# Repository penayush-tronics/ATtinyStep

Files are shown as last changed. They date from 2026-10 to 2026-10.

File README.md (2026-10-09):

# ATtinyStep

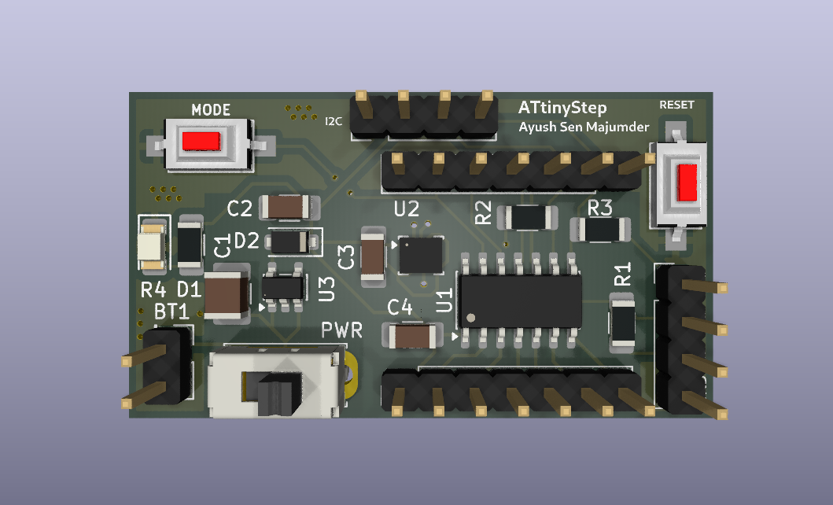
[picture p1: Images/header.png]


ATtinyStep is a compact, rechargeable, and portable offline step counter as well as speedometer. It helps in reaching your step goals at a healthy pace, while enjoying the outside world instead of doomscrolling with your neck down. It uses a 6-axis Accelrometer+Gyro IMU (Interital Measurment Unit) and the processing capabilities of the ATtiny1624 to easily count your steps automatically. As a bonus, it doubles as breakout board for the ATtiny1624, so it can be used for more projects other than a speedometer.

## How to use the ATtinyStep
Here is a labelled diagram:

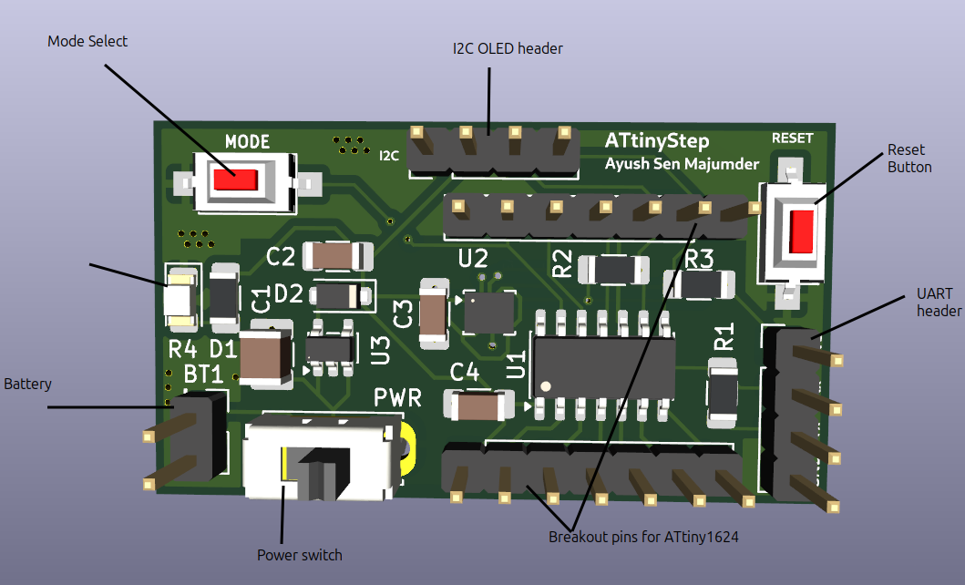
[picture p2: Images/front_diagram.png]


#### As step counter
Connect a single cell 3.7V li-ion battery to the battery header (with correct polarity; labelled on the back). It has an built-in voltage. After that, connect the I2C OLED screen. To use it as a step counter, flip the switch to turn it on. 
On the top left corner is a Mode select button, which allows the selection between speed display and step counting modes.
On the top right corner there is a Reset button to reset the Attiny chip in case of some error/restart. Below this button is the UART programming header, labelled for convenience. 
The device will automatically start counting steps and calculating the speed of your walking or any motion. 

#### As development board
You can also use it as a breakout board for the ATtiny1624 with built in 6-axis Gyro+Accelerometer and easy to use I2C header.
When powering it as a development board, make sure to use only **3V3 power (3.3V)**, on the VCC pin either on the breakout pins, the programming header, or the I2C header. Make sure to connect GND-Ground too. **Be careful with polarity**.
Pins 8 and 9 are always pulled high due to the I2C, so use them primarily for I2C. 
Pin 13 is connected to the onboard Mode Select button, using active low. This pin can be reconfigured.
Use the reset button to restart the Attiny1624.

#### Programming
ATtinyStep uses UPDI programming for the ATtiny1624, via UART. Make sure to use 3V3 only.
An appropriate resistor is already placed in series with Tx, so an external series resistor is not required, only a UART to USB converter is needed for programming. 
Connect the GND VCC pins, and connect **UART-USB Rx to ATtinyStep Tx, and Tx to Rx, like cris-cross**.
After that it can be programmed using ArduinoIDE with the **MegaTinyCore board library**.   

### Labels
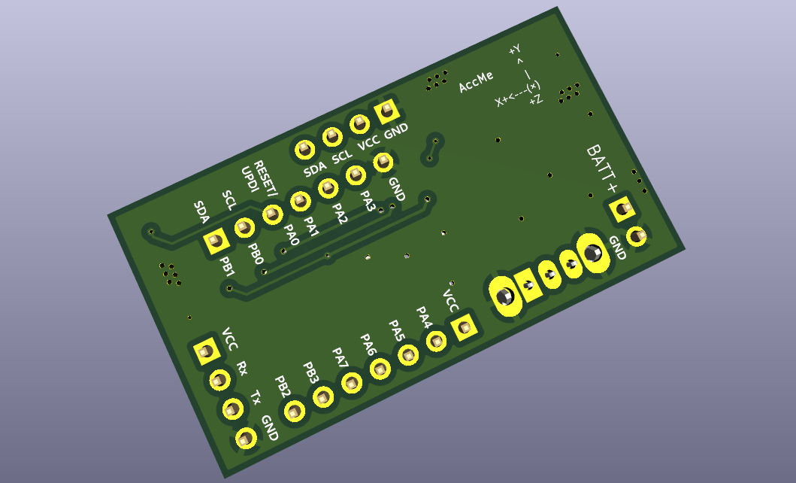
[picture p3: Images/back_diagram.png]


The board is thoroughly labelled with all components and pins labelled.
Here you can see the breakout pin labels, header labels, battery label **-- PLEASE DONT PUT REVERSE POLARITY--** , and accelerometer direction label.
Use these as a guide for usage. 

## How does it work
The ATinyStep works by letting the ATtiny1624 continuously gather angular orientation and acceleration data. By comparing these continuous values to known patterns, such as walking with it in your hand or pocket, it can accuratley detect a step. These actions create very specific accelration and rotation patterns, hence they can be used as reference. For example, walking with it in your hand will result in a big arc-like path, with maximum acceleration at the edges of the arc, and least in the center. This also is how your mobile device, like a phone, counts steps. The sensor being used here is from the LSM6DS series by STMicroelectronics, where the 6 stands for 6-axis. Six-axis means three-axis accelrometer and three-axis gyroscope. 

## Schematics 
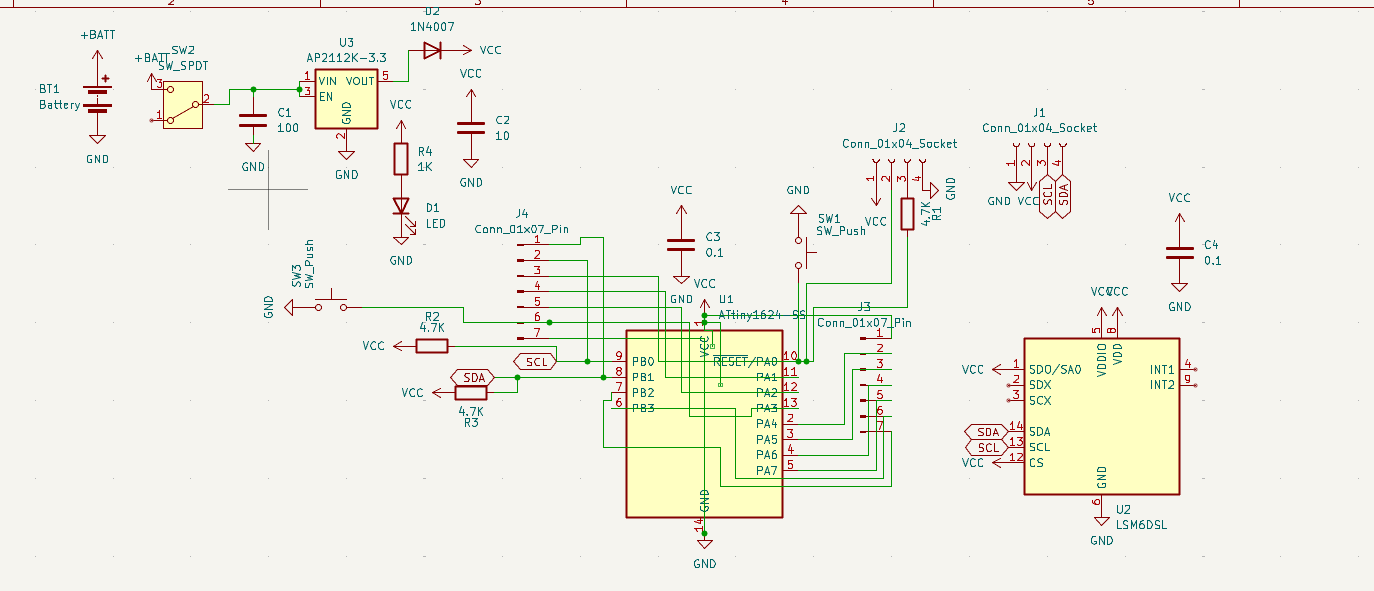
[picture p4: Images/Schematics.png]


KiCAD schematics can be found [here](PCB_Files/ATtinyStep.kicad_sch)

## PCB design

#### Front side:
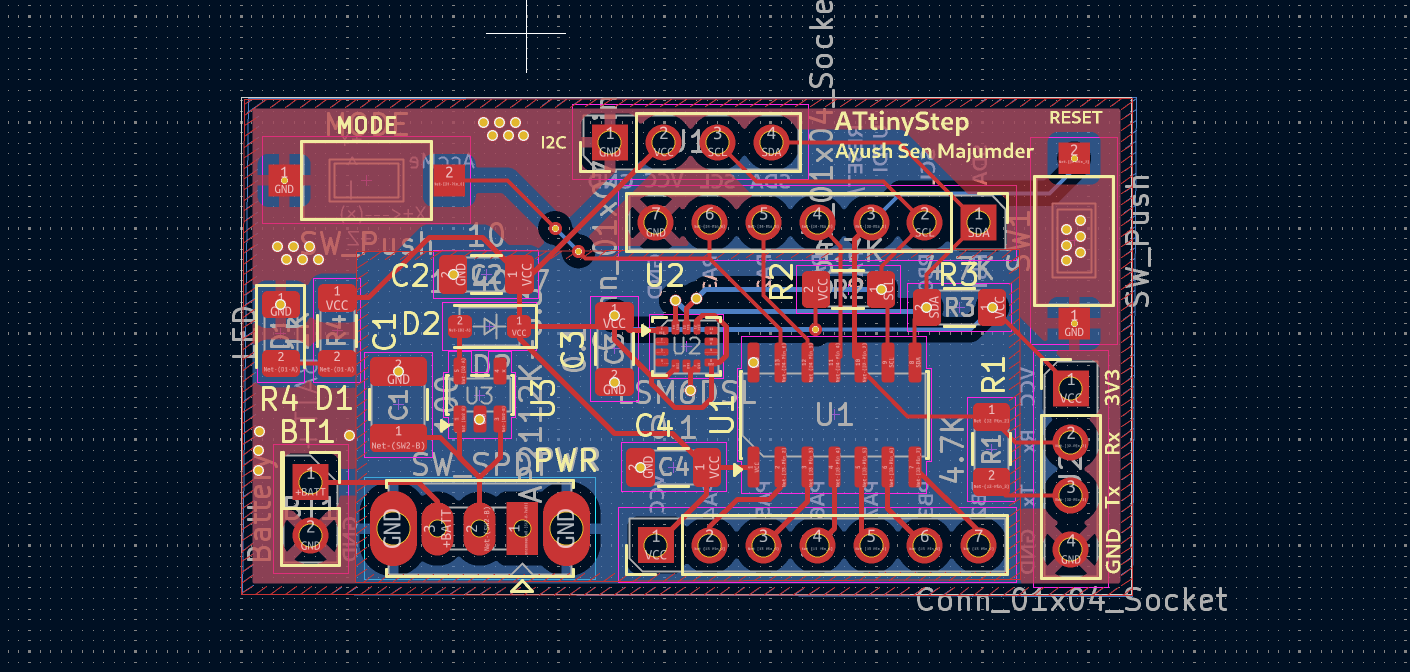
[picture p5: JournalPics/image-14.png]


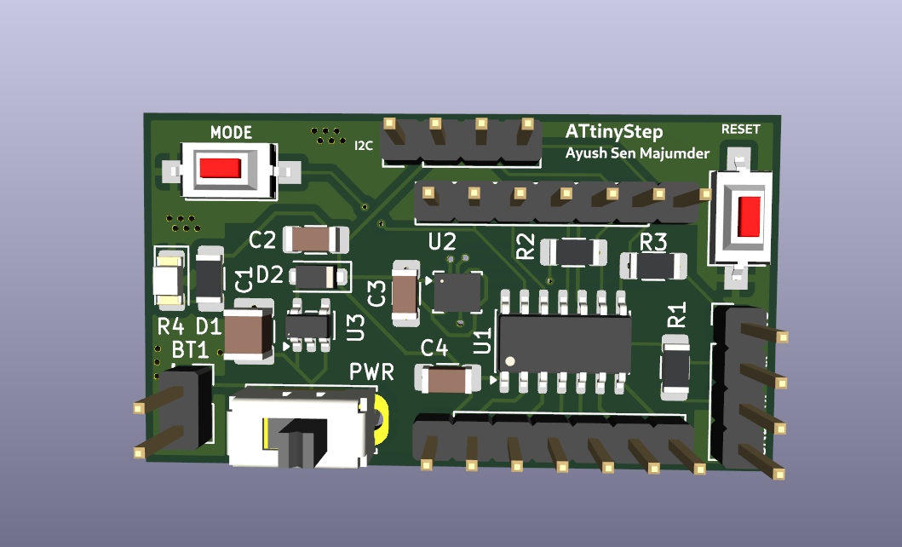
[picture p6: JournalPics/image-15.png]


#### Back side:
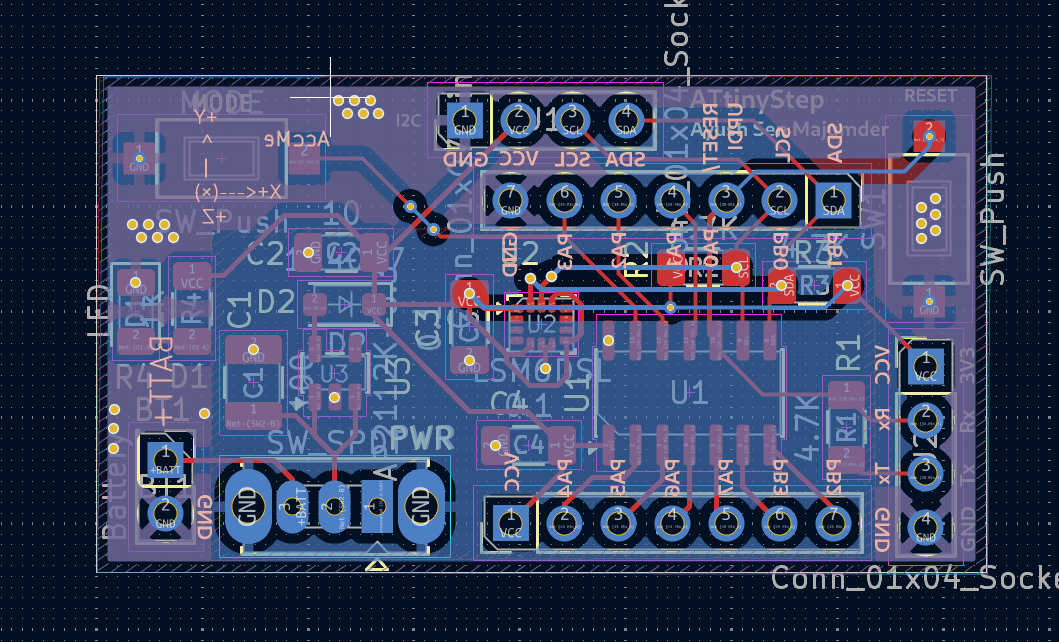
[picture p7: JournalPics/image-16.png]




KiCAD PCB design can be found [here](PCB_Files/ATtinyStep.kicad_pcb).
Gerber files for fabrication are [here](PCB_Files/ATtinyStep-Gerbers.zip).
Position file for pick and place is [here](PCB_Files/ATtinyStep-all.pos).

## Why ATtinyStep exists
One day I was walking around my community and talking to my friend online. We were talking about walking as an exercise, and how walking faster is important. Hence, they said that they were sure I wasn't walking fast enough. I told them I walk at 6km/h, but they did not believe me. That day I had two realisations: I should take a break from my phone during walks, and I need a speedometer for myself. So, this idea was born. An offline hardware speedometer. So I can make sure I am walking at a healthy speed.
The name comes from when I was thinking about a title, and realised ATtiny sounds like 'A tiny', and well it's a step counter. So ATtinyStep came. It is pronounced 'Ay Tee tiny step' or just 'A tiny step'.

The extra breakout board pins were because it felt like a waste to have so many pins unused. So the breakout enables them to be used. 

## Demo
Coming soon :)

## Bill Of Materials (BOM)

| Sr No. | Component Description | Min Order Qty | Qty for Board | Unit Price (INR) | Ext. Price (INR) | Reference Link |
|---|---|---|---|---|---|---|
| 1 | ATTINY1624-SSU-MICROCHIP-8 Bit MCU | 1 | 1 | 226.00 | 226.00 | [Robu](https://robu.in/product/attiny1624-ssu-microchip-8-bit-mcu-avr-family-attiny1624-series-microcontrollers-avr-20-mhz-16-kb-14-pins-wsoic/) |
| 2 | LSM6DSOETR3-Stmicroelectronics | 1 | 1 | 292.00 | 292.00 | [Robu](https://robu.in/product/lsm6dsoetr3-stmicroelectronics-lsm6dsoetr3-mems-modules/) |
| 3 | 0.96 inch Yellow-Blue OLED Display Module | 1 | 1 | 179.00 | 179.00 | [Robu](https://robu.in/product/0-96-inch-yellow-yellow-blue-oled-lcd-led-display-module/) |
| 4 | AP2112K/AP2125K -3.3TRG1-Diodes Incorporated | 1 | 1 | 13.00 | 13.00 | [Robu](https://robu.in/product/ap2125k-3-3trg1-diodes-incorporated-300ma-65db-fixed-3-3v-positive-9v-sot-23-5-voltage-regulators-linear-low-drop-out-ldo-regulators-rohs/) |
| 5 | 3.7V 1500mAH Li-Po Rechargeable Battery (523450) | 1 | 1 | 232.00 | 232.00 | [Quartz Components](https://quartzcomponents.com/products/3-7v-1500mah-li-po-rechargeable-battery-523450?variant=44853316813034) |
| 6 | Toggle Slide Switch | 1 | 1 | 5.00 | 5.00 | [Quartz Components](https://quartzcomponents.com/products/toggle-slide-switch?variant=31898088833159) |
| 7 | Green LED - SMD (1206 Package) - Pack of 50 | 50 | 1 | 0.72 | 36.00 | [Quartz Components](https://quartzcomponents.com/collections/all/products/green-led-smd-1206-package-pack-of-50) |
| 8 | 1K Ohm 1206 Package 1/4W SMD Resistor 5% Tolerance (Pack of 20 Pieces) | 20 | 1 | 0.50 | 10.00 | [Quartz Components](https://quartzcomponents.com/products/1k-ohm-1206-package-1-4w-smd-resistor-5-tolerance-pack-of-20-pieces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) |
| 9 | 4.7K Ohm 1206 Package 1/4W SMD Resistor 5% Tolerance (Pack of 20 Pieces) | 20 | 3 | 0.60 | 12.00 | [Quartz Components](https://quartzcomponents.com/products/4-7k-ohm-1206-package-1-4w-smd-resistor-5-tolerance-pack-of-20-pieces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) |
| 10 | TSB005A2518B-BZCN-3.6mm 2.5mm 50mA 8mm 30,000 Times 180gf 12V SMD Tactile Switches | 4 | 2 | 2.85 | 11.40 | [Robu](https://robu.in/product/tsb005a2518b-bzcn-3-6mm-2-5mm-50ma-8mm-30000-times-180gf-12v-smd-tactile-switches-rohs/) |
| 11 | A7 / 1N4007 SMD Diode (Pack of 10) | 10 | 1 | 1.10 | 11.00 | [Quartz Components](https://quartzcomponents.com/products/m7-1n4007-smd-diode-pack-of-11?variant=43690452713706) |
| 12 | 100nF / 0.1uF (104) 50V 1206 SMD Capacitor (Pack of 10 Pieces) | 10 | 2 | 1.60 | 16.00 | [Quartz Components](https://quartzcomponents.com/products/100nf-0-1uf-104-50v-1206-smd-capacitor-pack-of-10-pieces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) |
| 13 | 16V 10uF X5R 1206 Multilayer Ceramic Capacitors MLCC | 3 | 2 | 4.57 | 13.71 | [Robu](https://robu.in/product/cl31a106kohnnwe-samsang-16v-10uf-x5r-1206-multilayer-ceramic-capacitors-mlcc-smd-smt-rohs/) |
| 14 | MLCC SMD Capacitor - 100UF, 10V, 1210 | 1 | 1 | 46.00 | 46.00 | [Robu](https://robu.in/product/lmk325abj107mm-p-taiyo-yuden-cap-smd-mlcc-100uf-10v-1210-pack-of-1/) |
| 15 | TP4056 - Battery Charging | 1 | 1 | 14.00 | 14.00 | [Quartz Components](https://quartzcomponents.com/products/tp4056-battery-charging-micro-usb) |
| 16 | Male/Female headers | 1 | 1 | 9.00 | 9.00 | [Robu](https://robu.in/product/2-54mm-1x40-pin-male-single-row-straight-short-header-strip-pack-of-3/) |
| 17 | Custom PCB | 5 | 1 | 188.80 | 944.00 | [Lion Circuits](https://www.lioncircuits.com/quote?layers=2&units=5&dimensionX=50&dimensionY=20) |
|  | Totals: |  | 22 | 1226.96 | 2070.11 |  |

Price per board: ~1230 INR or ~ $12.9 USD

The spreadsheet BOM is [here](ATtinyStepBOM.xlsx)

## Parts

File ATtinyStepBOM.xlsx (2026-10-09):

Sr No. | Component Description | Min Order Qty | Qty for board | Unit Price (INR) | Ext. Price (INR) | Reference Link
1 | ATTINY1624-SSU-MICROCHIP-8 Bit MCU | 1 | 1 | 226 | 226 | https://robu.in/product/attiny1624-ssu-microchip-8-bit-mcu-avr-family-attiny1624-series-microcontrollers-avr-20-mhz-16-kb-14-pins-wsoic/
2 | LSM6DSOETR3-Stmicroelectronics | 1 | 1 | 292 | 292 | https://robu.in/product/lsm6dsoetr3-stmicroelectronics-lsm6dsoetr3-mems-modules/
3 | 0.96 inch Yellow-Blue OLED Display Module | 1 | 1 | 179 | 179 | https://robu.in/product/0-96-inch-yellow-yellow-blue-oled-lcd-led-display-module/
4 | AP2112K/AP2125K -3.3TRG1-Diodes Incorporated | 1 | 1 | 13 | 13 | https://robu.in/product/ap2125k-3-3trg1-diodes-incorporated-300ma-65db-fixed-3-3v-positive-9v-sot-23-5-voltage-regulators-linear-low-drop-out-ldo-regulators-r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
5 | 3.7V 1500mAH Li-Po Rechargeable Battery (523450) | 1 | 1 | 232 | 232 | https://quartzcomponents.com/products/3-7v-1500mah-li-po-rechargeable-battery-523450?variant=44853316813034
6 | Toggle Slide Switch | 1 | 1 | 5 | 5 | https://quartzcomponents.com/products/toggle-slide-switch?variant=31898088833159
7 | Green LED - SMD (1206 Package) - Pack of 50 | 50 | 1 | 0.72 | 36 | https://quartzcomponents.com/collections/all/products/green-led-smd-1206-package-pack-of-50
8 | 1K Ohm 1206 Package 1/4W SMD Resistor 5% Tolerance (Pack of 20 Pieces) | 20 | 1 | 0.5 | 10 | https://quartzcomponents.com/products/1k-ohm-1206-package-1-4w-smd-resistor-5-tolerance-pack-of-20-pieces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
9 | 4.7K Ohm 1206 Package 1/4W SMD Resistor 5% Tolerance (Pack of 20 Pieces) | 20 | 3 | 0.6 | 12 | https://quartzcomponents.com/products/4-7k-ohm-1206-package-1-4w-smd-resistor-5-tolerance-pack-of-20-pieces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
10 | TSB005A2518B-BZCN-3.6mm 2.5mm 50mA 8mm 30,000 Times 180gf 12V SMD Tactile Switches | 4 | 2 | 2.85 | 11.4 | https://robu.in/product/tsb005a2518b-bzcn-3-6mm-2-5mm-50ma-8mm-30000-times-180gf-12v-smd-tactile-switches-rohs/
11 | A7 / 1N4007 SMD Diode (Pack of 10) | 10 | 1 | 1.1 | 11 | https://quartzcomponents.com/products/m7-1n4007-smd-diode-pack-of-11?variant=43690452713706
12 | 100nF / 0.1uF (104) 50V 1206 SMD Capacitor (Pack of 10 Pieces) | 10 | 2 | 1.6 | 16 | https://quartzcomponents.com/products/100nf-0-1uf-104-50v-1206-smd-capacitor-pack-of-10-pieces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
13 | 16V 10uF X5R 1206 Multilayer Ceramic Capacitors MLCC | 3 | 2 | 4.57 | 13.71 | https://robu.in/product/cl31a106kohnnwe-samsang-16v-10uf-x5r-1206-multilayer-ceramic-capacitors-mlcc-smd-smt-rohs/
14 | MLCC SMD Capacitor - 100UF, 10V, 1210 | 1 | 1 | 46 | 46 | https://robu.in/product/lmk325abj107mm-p-taiyo-yuden-cap-smd-mlcc-100uf-10v-1210-pack-of-1/
15 | TP4056 - Battery Charging | 1 | 1 | 14 | 14 | https://quartzcomponents.com/products/tp4056-battery-charging-micro-usb
16 | Male/Female headers | 1 | 1 | 9 | 9 | https://robu.in/product/2-54mm-1x40-pin-male-single-row-straight-short-header-strip-pack-of-3/
17 | Custom PCB | 5 | 1 | 188.8 | 944 | https://www.lioncircuits.com/quote?layers=2&units=5&dimensionX=50&dimensionY=20
 | Totals: |  | 22 | 1226.96 | 2070.11

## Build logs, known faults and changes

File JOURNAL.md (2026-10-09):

---
title: "ATtinyStep"
author: "Ayush Sen Majumder"
description: "An ATtiny powered step counter and speed/distance measuring device that fits in the palm of your hand."
created_at: "2026-10-05"
---

# October 5

After a few days of rumination, my idea for this step counter is finally refined and ready for me to pursue. My inital idea was just a device to tell me how fast I was walking during my exercise, because speed does matter. Incline too. Hence  this idea came. After some thinking I thought of adding some step counting, distance measuring too. 

Now that requried features are there, I needed a cheap and appropriate processor. An arduino nano is too over-powered for this, while a ATtiny13a does not have enough ram. So I researched and found the ATtiny16 series, which has 16KB of flash and 2KB of memory. 

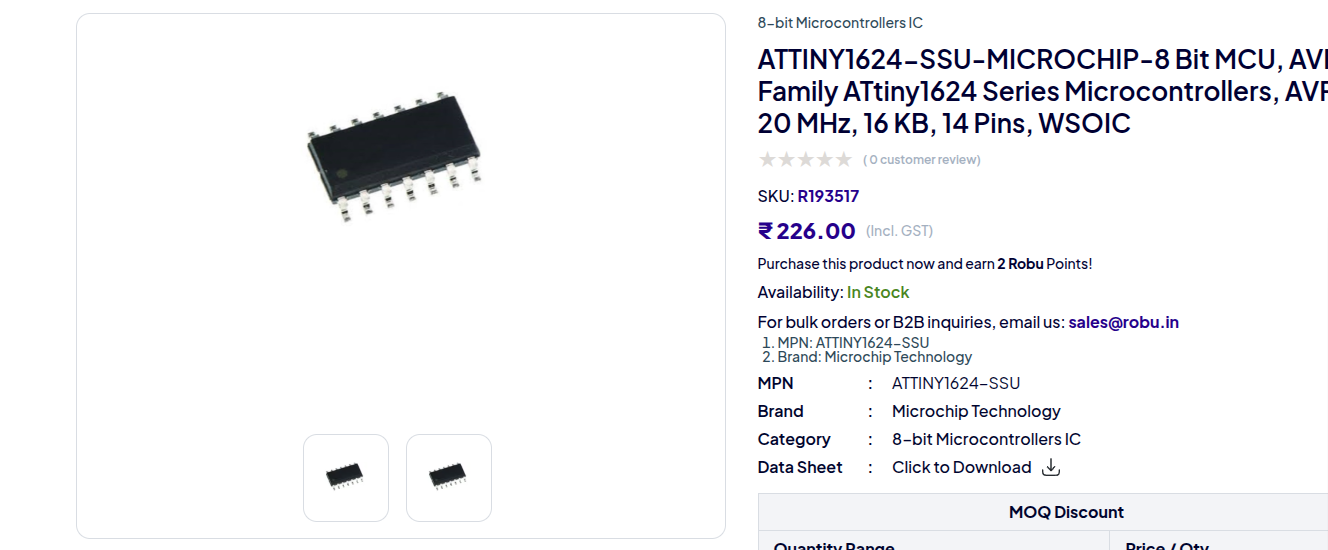
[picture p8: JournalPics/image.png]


It is perfect for the needed calculations, as well as being simple enough for this project. Some other versionsa re there like the ATtiny8 series, but the RAM is not enough in some cases, and in others the price is more than this ATtiny1624. 

It has I2C, which means I can eaisly use peripherals. I wanted to use an I2C OLED screen for output, hence this is perfect. 

To measure all speed, steps, and distance, I need an IMU or an Intertial Meausrment Unit. For this project I need a 6-axis IMU, meaning a 3-axis accelerometer as well as a 3-axis gyroscope. The cheapest one I could find was the LSM6DS series: 

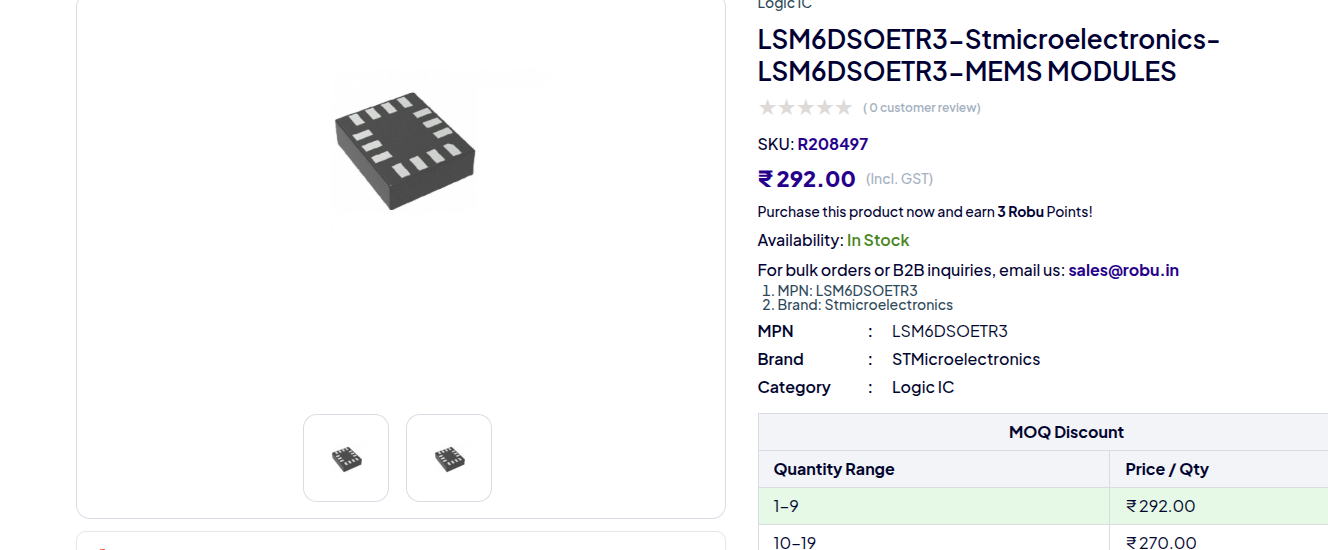
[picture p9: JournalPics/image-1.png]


For some weird reason, IMUs are insanely expensive. Tough to find a cheap one thats 6-axis. This one is LGA, which I have never soldered before, so this will be a new challenge for me. 

Next I will do the schematics and then build pcb. After that I need funding to order parts and PCB, then I can build this project and use it. The plan is pretty clear, and im aching to execute it. 

Note: I did not know i needed a Lapse timelapse for research, so there is no lapse for this. 

**Total time spent: 1 hour**

# October 6

## Making schematics

Today I made the schematic for the device. I thought it wouldn't be that much of a hassle, but it was nonetheless. I forgot i needed a power circuit, because i thought everything would work off of a LiPo, and also realised there were so many pins on the ATtiny going to waste. 

Here is the schematic right now: 

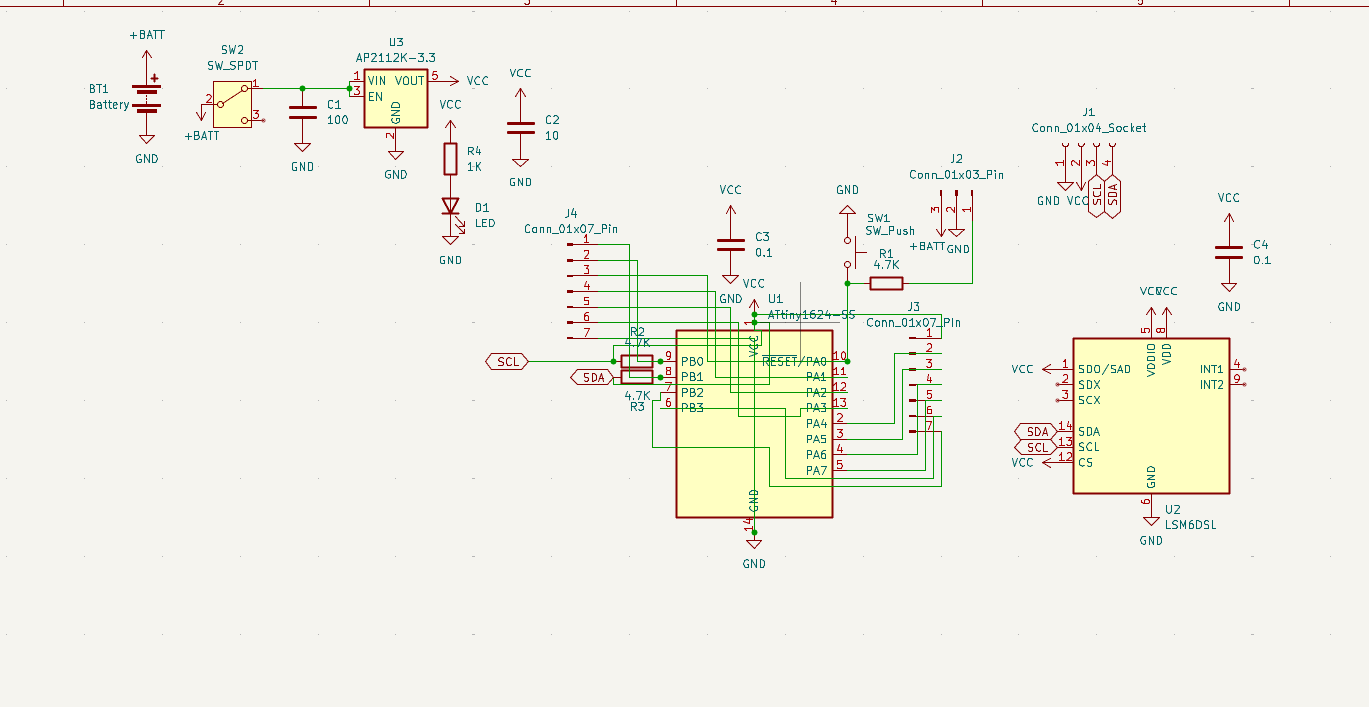
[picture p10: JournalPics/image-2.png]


In the top left corner is a simple standard power circuit: 

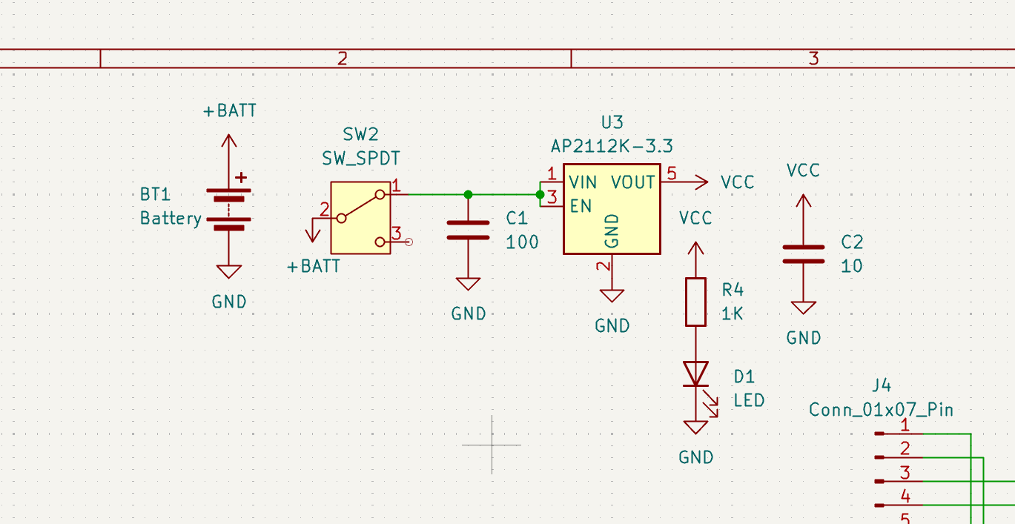
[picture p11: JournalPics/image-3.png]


I am using an AP2112K-3.3V LDO to step down the battery voltage to 3.3V. Along with this is a switch, some capacitors and a status LED. 
Had to add this because the IMU will no work off the battery directly, too high of a voltage. 

Next i added schematics for the ATtiny1624:

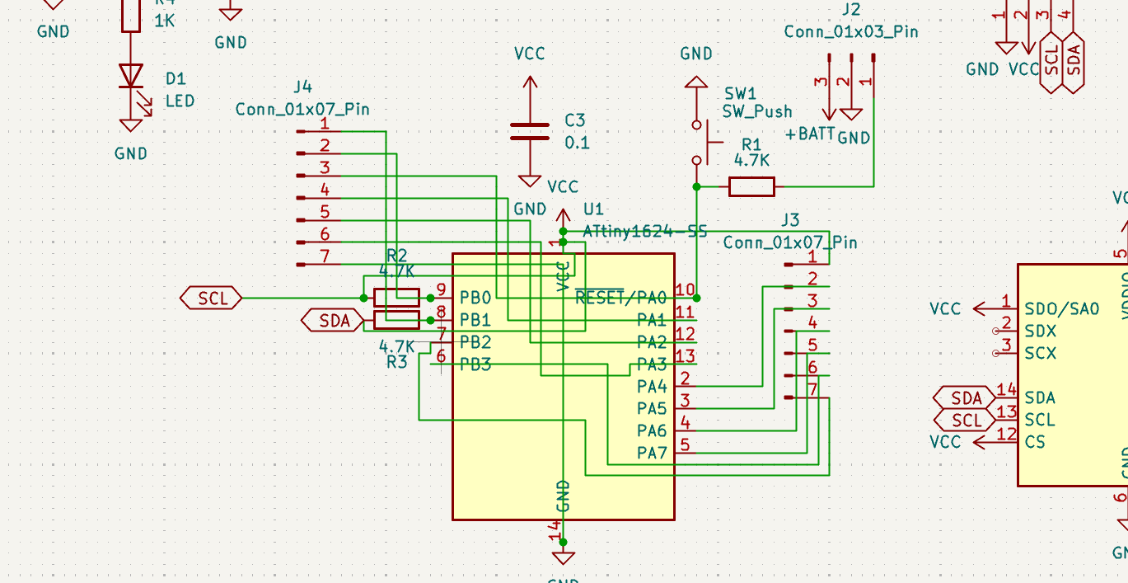
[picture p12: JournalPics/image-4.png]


Wired up a reset button, a programming header, the I2C lines for OLED and IMU. Added resistors for the I2C and UPDI programming. I also added some breakout pins because it felt like the rest of the chip was going to waste when im using just 2 pins to drive peripherals. so an optional breakout is there now. Hence the mess of wires. 

Finally schematics for the IMU: 

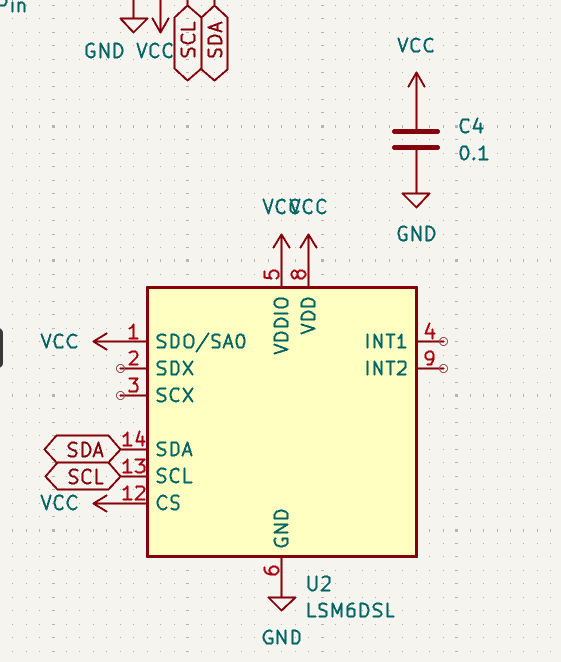
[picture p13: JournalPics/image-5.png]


Just two I2C pins, and every other connection is pulled high for the correct setup. 

Thats about it for the schematic, ill make the PCB next

Lapse: https://lapse.hackclub.com/timelapse/I2aO08c73dfr

**Total time spent: 1 hour**

# October 7

## Designing PCB

I designed the PCB today. It tooke me a while to design this because I had to really do a lot of space management. For the current deisgn I am 'satisfied' but I think it can be better. I only made it single sided so i can solder it usign just my hotplate; no double side hassle even thought double might have been easier to design. 
Here is the PCB:
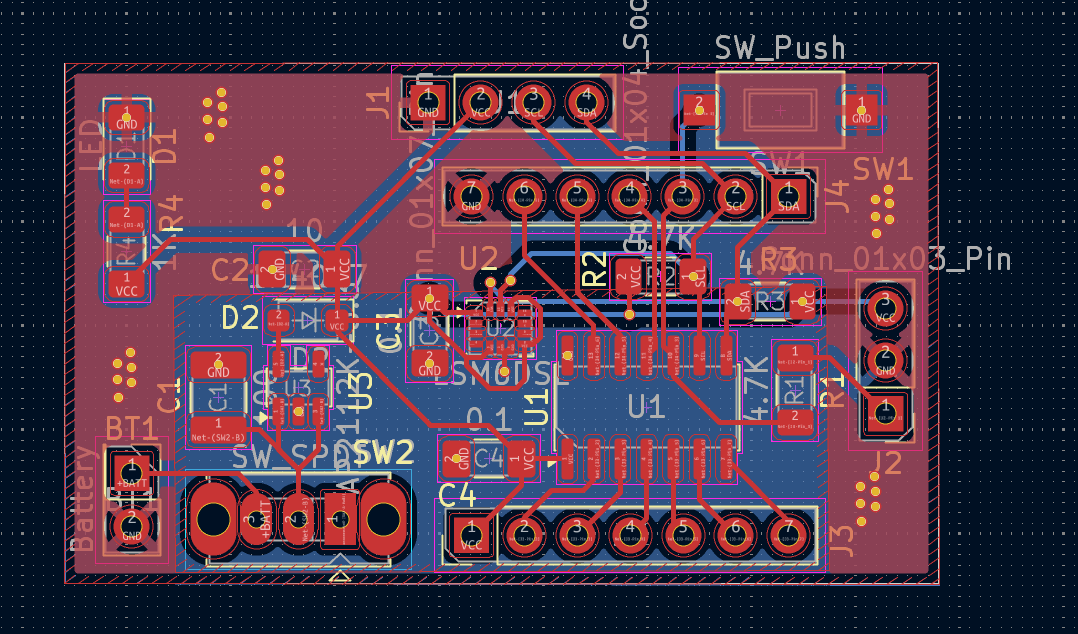
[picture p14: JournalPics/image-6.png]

Added a few parts like a switch, to turn the device on and off. 

I also added a diode:
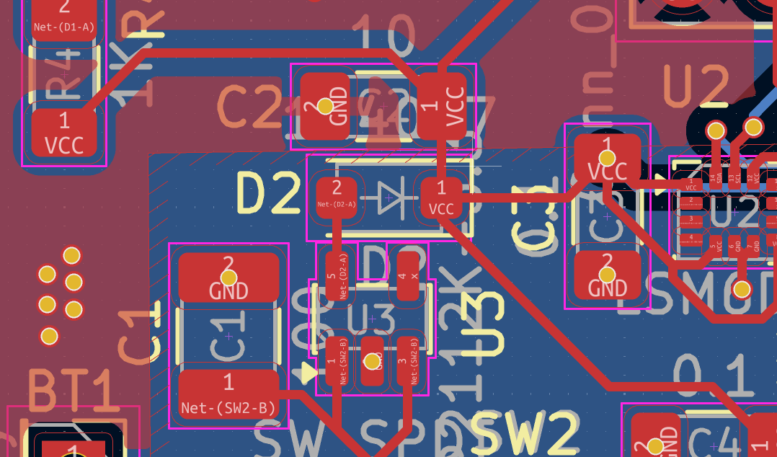
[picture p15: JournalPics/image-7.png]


this diode prevents current from entering the LDO in reverse when it's powered by the programmer on the programmign header. 
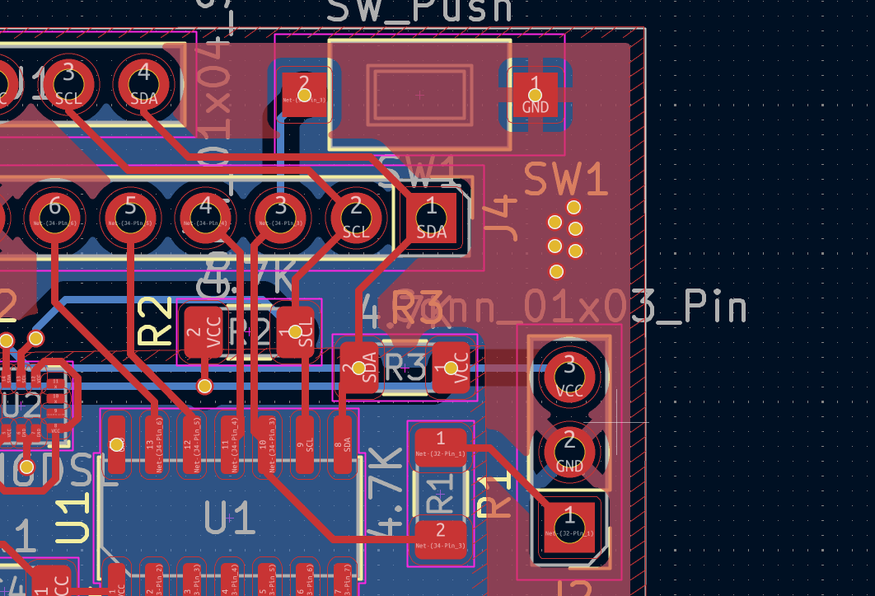
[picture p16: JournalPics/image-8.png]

The right three-pin is the programming header, the top button is a reset button for the ATtiny. Up there is a four-pin for the OLED screen. 

The most annoyign part was wiring the I2C lines. I had to route them from the back which was annoying and felt asymmetrical. 
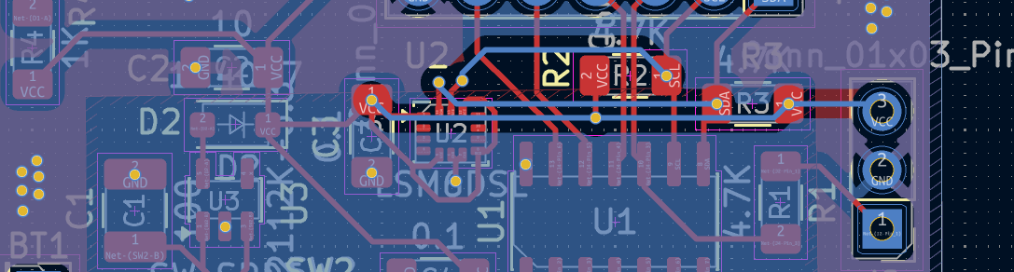
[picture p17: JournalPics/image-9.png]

As you can see, where blue is backside. 

Another annoying thing was power VCC connections. I couldnt use a power plane because ground plane more important, and frontside there is no place for a power plane. I actually had to remove a rectangle of the ground plane because it had thin parts which would only capture noise instead of remove it. 

A key thing which i did was to center the IMU. This is important for accurate angle readings and measuring acceleration. I did this by measuring the board dimensions and approximately halving them, and putting guides. 

Here is a 3d view: 
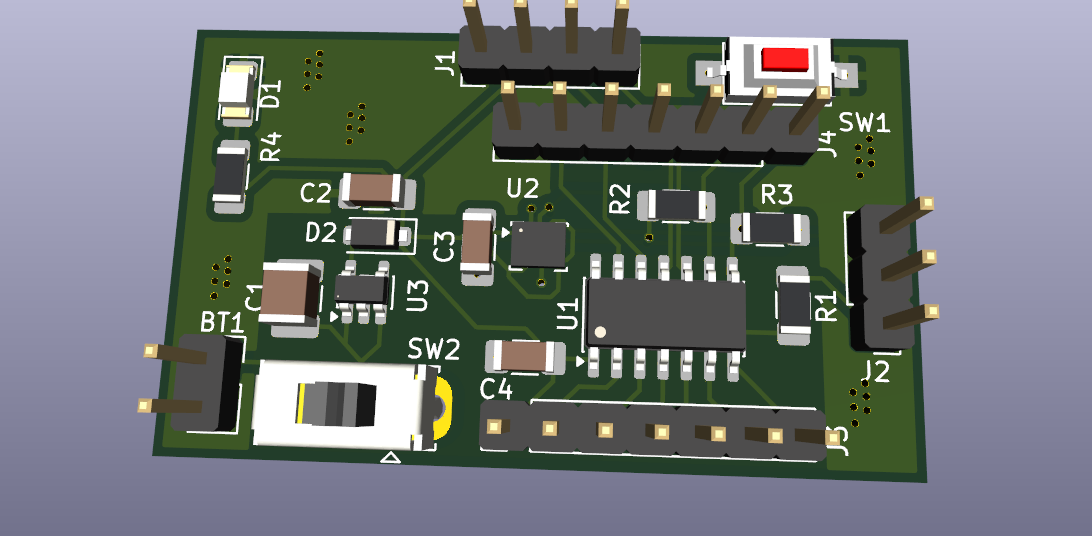
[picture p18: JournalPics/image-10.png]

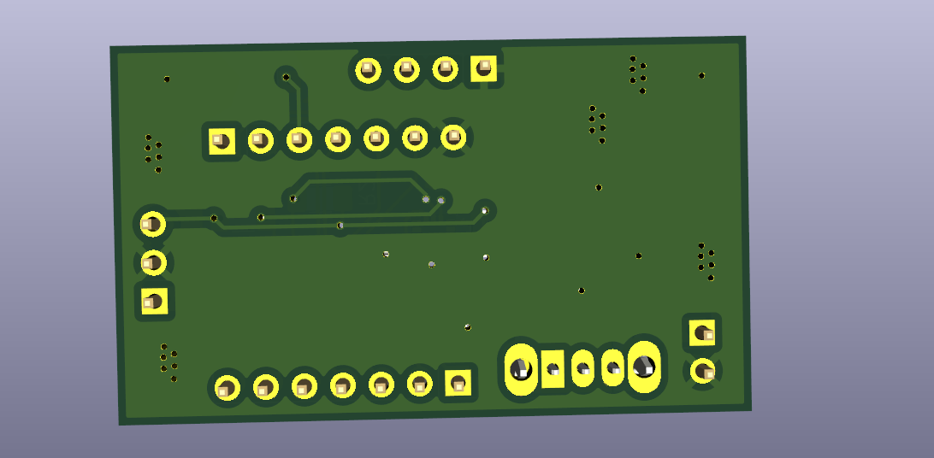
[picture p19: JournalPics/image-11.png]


Next is refining PCB, panelising for efficient fabrication, and then repo updating and shipping. 

Lapse: https://lapse.hackclub.com/timelapse/N_VsGccL-1x6

**Total time spent: 1.5 hours**

# October 8

  ## Fixing the PCB

I was looking over the PCB for some time, and there were a few crucial mistakes i had to fix, and i made the PCB smaller. I am actually happy with this design now, it looks much better than before. 
### Mistake 1: breakout pin placement
Before, the breakout pin placements were almost random. the two rows were not aligned with 2.54mm pitch standard. So i had to use another header row as a guide and arrange them. This meant i hd to brign the top one closer, so i had to rearrnage the I2C resistors. Now it is alligned!.

### Mistake 2: UPDI programming pins
I didnt realise UPDI programming puts a resistor only on the Tx, so i had placed a resistor in series with the UPDI pin itslef! It would have been impossible to program the chip if i had done that. I fixed it now by editing the schematics and adding Tx Rx pins, and adding a resistor to only the Tx.
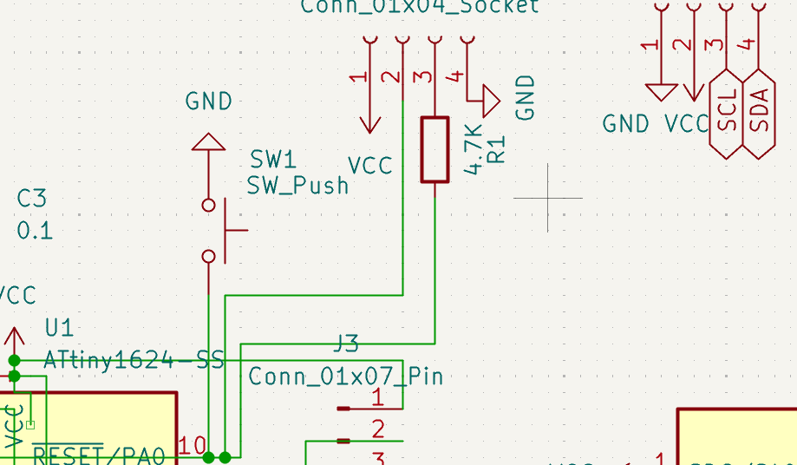
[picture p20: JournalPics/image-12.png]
 

### other edits
i resized the board to be smaller heightwise, because it just felt like a waste of space. I rearrnaged eveyrthing, i recentred the IMU, this time with much better accuracy. 
I added a mode select button to pin 6 on the attiny, so that it can be controlled a little. 
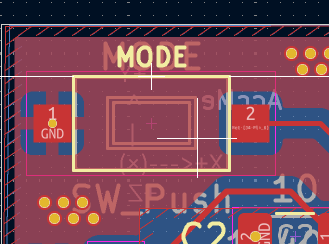
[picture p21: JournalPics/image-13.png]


it looks really nice now, especially because i labelled everything on the PCB. I added a accelrometer direction diagram too, some pin names and other things for usability and readability. Most importantly i added labels for battery input; reverse polarity would kill everything. 
 take a look at the updated PCB!

 front:
  
  
 
 back:
  
  

 I am really happy with this. Of course i will do another check before fabrication. But right now its beutiful. 

 Lapse: https://lapse.hackclub.com/timelapse/U3Mb4CTaFlST

**Total time spent: 1.5 hours**

# October 9
  ## Project is shipped on GitHub!
  I finally shipped the project on github. The BOM and everything is there i made BOM i made readme. Im too sleepy to write anything now. Hackatime and Lapse tracked me, but the README was also tracked by Hackatime at same time as Lapse. so ill deflate my jorunal time here so that the hackatime time is accurate and im not overstating time. 

  Here is the repo now:
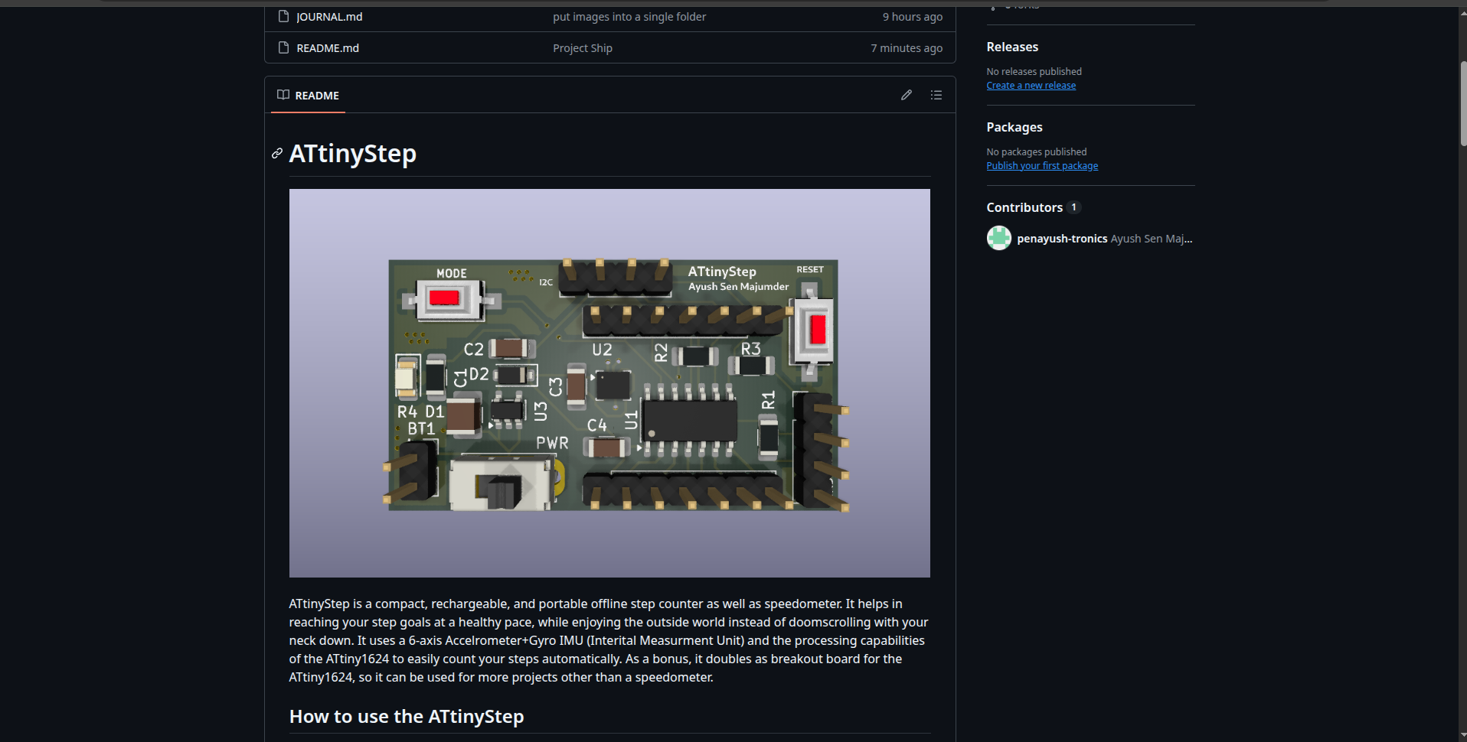
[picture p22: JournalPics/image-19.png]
  

   I added how to use:
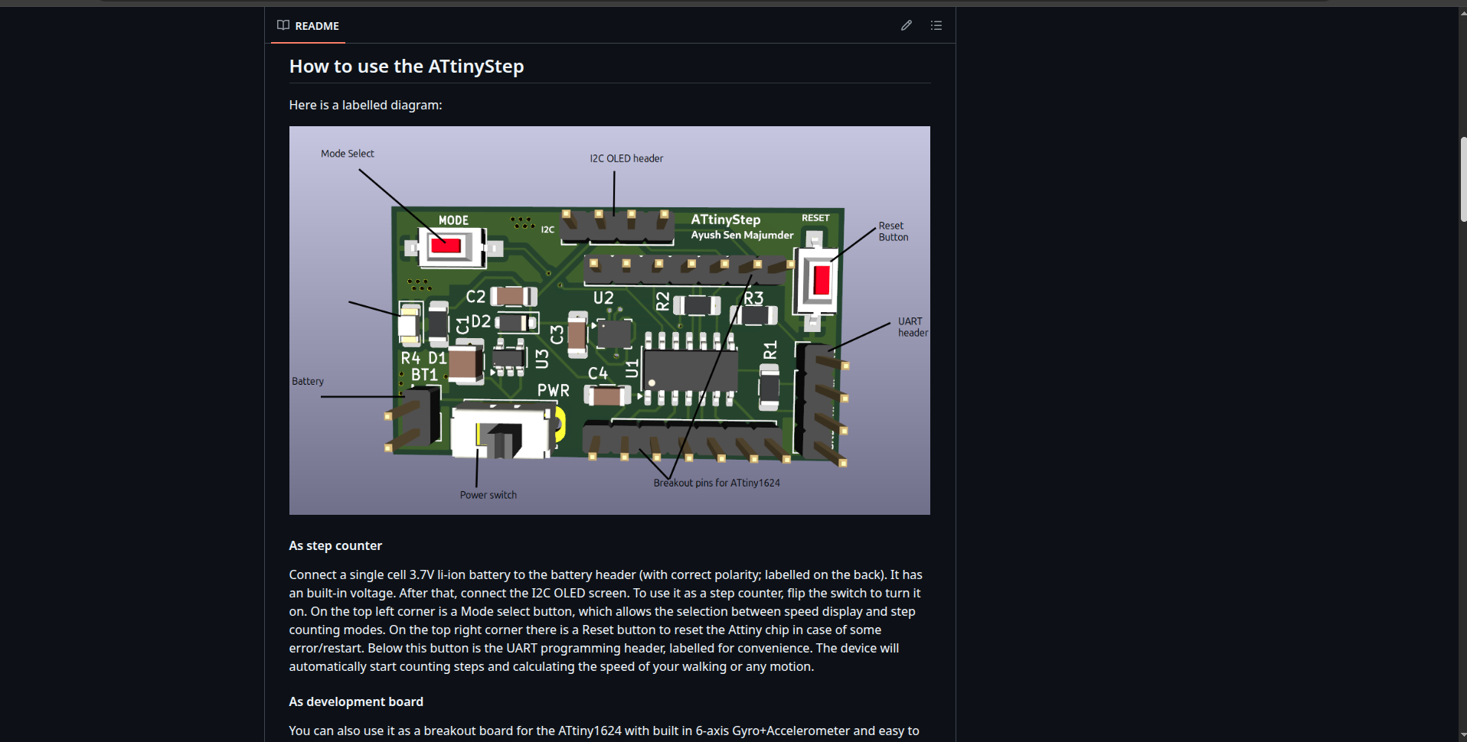
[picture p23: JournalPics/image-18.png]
   

   BOM:
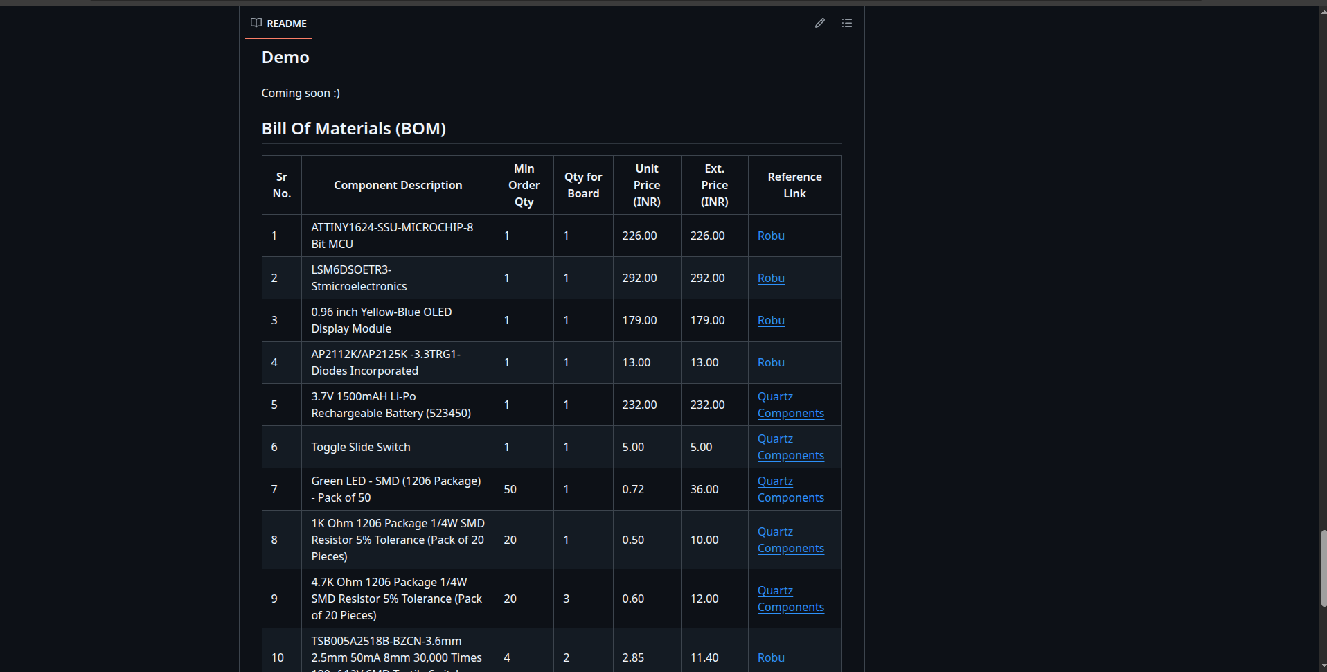
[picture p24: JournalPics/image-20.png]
   

   Lapse: https://lapse.hackclub.com/timelapse/evV-MM8G5bpx

   So i have 2h on lapse and 1h 24 min on hackatime for README. so 1.5h hackatime 0.5h journal rounded roughly.

**Total time spent: 0.5 hours**

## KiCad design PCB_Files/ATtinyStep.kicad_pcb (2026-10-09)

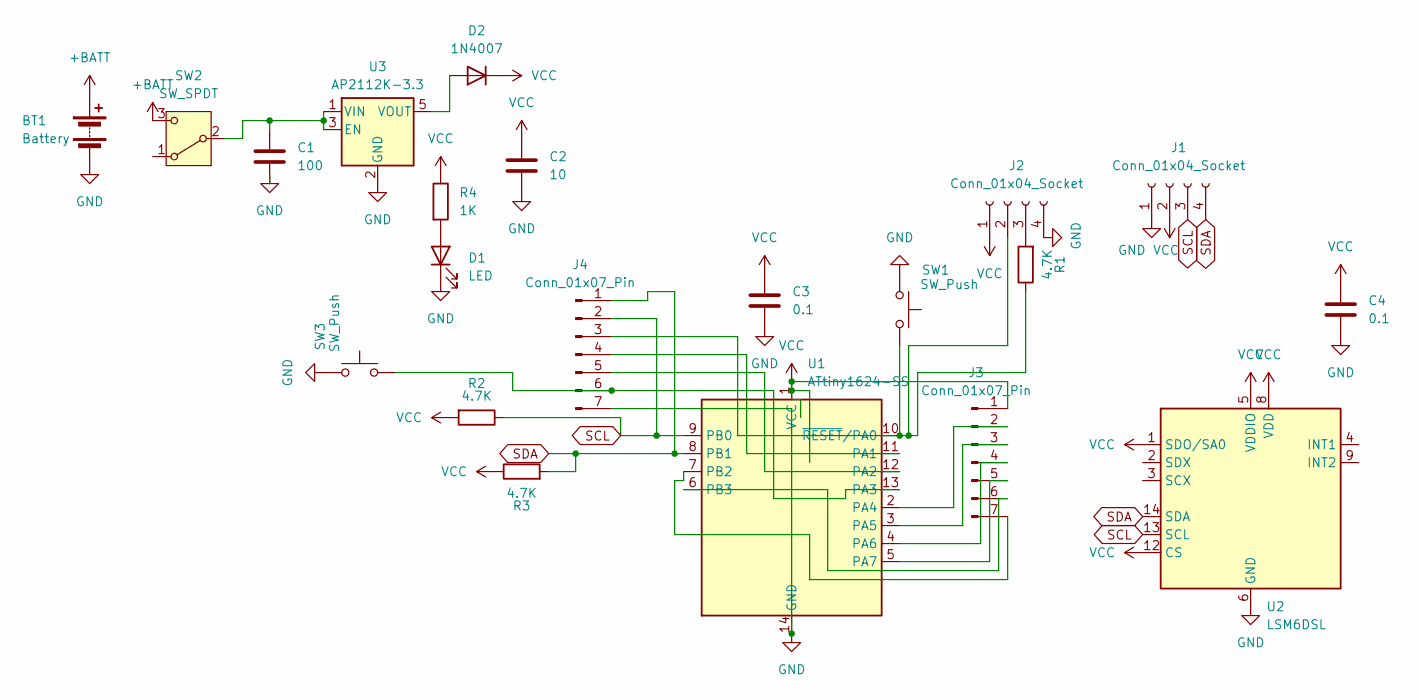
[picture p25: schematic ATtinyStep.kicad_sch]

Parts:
BT1: Battery; PinHeader_2x01_P2.54mm_Vertical
C1: 100; C_1210_3225Metric_Pad1.33x2.70mm_HandSolder
C2: 10; C_1206_3216Metric_Pad1.33x1.80mm_HandSolder
C3, C4: 0.1; C_1206_3216Metric_Pad1.33x1.80mm_HandSolder
D1: LED; LED_1206_3216Metric
D2: 1N4007; D_SOD-123F
J1, J2: Conn_01x04_Socket; PinHeader_1x04_P2.54mm_Vertical
J3, J4: Conn_01x07_Pin; PinHeader_1x07_P2.54mm_Vertical
R1, R2, R3: 4.7K; R_1206_3216Metric_Pad1.30x1.75mm_HandSolder
R4: 1K; R_1206_3216Metric_Pad1.30x1.75mm_HandSolder
SW1, SW3: SW_Push; SW_SPST_CK_RS282G05A3
SW2: SW_SPDT; SW_Slide_SPDT_Straight_CK_OS102011MS2Q
U1: ATtiny1624-SS; SOIC-14_3.9x8.7mm_P1.27mm
U2: LSM6DSL; LGA-14_3x2.5mm_P0.5mm_LayoutBorder3x4y
U3: AP2112K-3.3; SOT-23-5

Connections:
+BATT: BT1.1 (+), SW2.3 (C); also elsewhere on the board
GND: BT1.2 (-), C1.2, C2.2, C3.2, C4.2, D1.1 (K), J1.1, J2.4, J4.7, SW1.1, SW3.1, U1.14 (GND), U2.6 (GND), U2.7 (GND), U3.2 (GND); also elsewhere on the board
unnamed: D1.2 (A), R4.2
unnamed: D2.2 (A), U3.5 (VOUT)
unnamed: J2.2, J4.3, R1.1, SW1.2, U1.10 (~RESET/PA0)
unnamed: J2.3, R1.2
unnamed: J3.2, U1.2 (PA4)
unnamed: J3.3, U1.3 (PA5)
unnamed: J3.4, U1.4 (PA6)
unnamed: J3.5, U1.5 (PA7)
unnamed: J3.6, U1.6 (PB3)
unnamed: J3.7, U1.7 (PB2)
unnamed: J4.4, U1.11 (PA1)
unnamed: J4.5, U1.12 (PA2)
unnamed 14: J4.6, SW3.2, U1.13 (PA3); also elsewhere on the board
unnamed 15: C1.1, SW2.2 (B), U3.1 (VIN), U3.3 (EN); also elsewhere on the board
SCL: J1.3, J4.2, R2.1, U1.9 (PB0), U2.13 (SCL)
SDA: J1.4, J4.1, R3.2, U1.8 (PB1), U2.14 (SDA)
VCC: C2.1, C3.1, C4.1, D2.1 (K), J1.2, J2.1, J3.1, R2.2, R3.1, R4.1, U1.1 (VCC), U2.1 (SDO/SA0), U2.5 (VDDIO), U2.8 (VDD), U2.12 (CS)

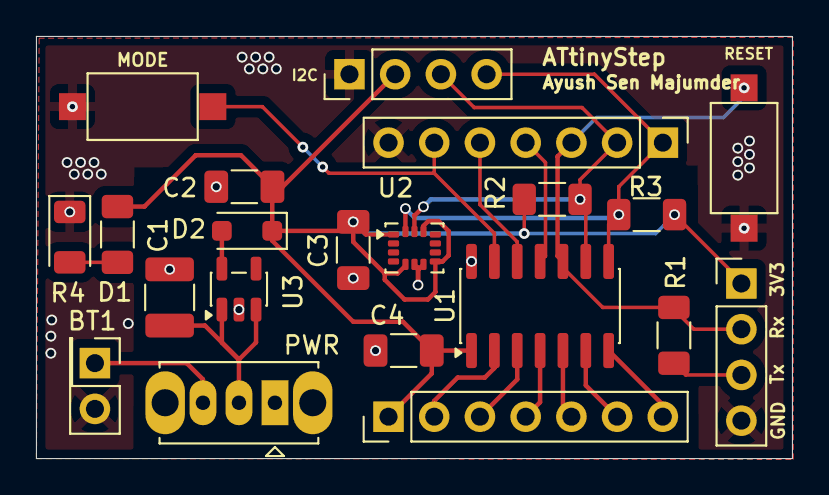
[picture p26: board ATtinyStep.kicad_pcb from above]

Board: 2 copper layers, 42.0 x 23.5 mm, 21 parts (0 on the bottom side), 19 nets.

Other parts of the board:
MODE: SW_Push; SW_SPST_CK_RS282G05A3
PWR: SW_SPDT; SW_Slide_SPDT_Straight_CK_OS102011MS2Q

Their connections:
+BATT: PWR.3 (C); also elsewhere on the board
GND: MODE.1; also elsewhere on the board
unnamed 14: MODE.2; also elsewhere on the board
unnamed 15: PWR.2 (B); also elsewhere on the board

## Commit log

2026-10-06 Added schematic journal
2026-10-09 Project Ship
    [ATtinyStep.kicad_pcb, ATtinyStep.kicad_sch, ATtinyStepBOM.xlsx]
2026-10-11 added BOM in csv format
2026-10-19 added USD BOM
2026-10-19 updated README BOM
